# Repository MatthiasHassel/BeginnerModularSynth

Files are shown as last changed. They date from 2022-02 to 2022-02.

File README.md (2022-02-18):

# BeginnerModularSynth
DIY Modular Synth based on the Bela Board

I built this DIY Modular Synth for my bachelor thesis in February 2022. It is based on the Bela Board from the Augmented Instruments Laboratory in London and Eurorack compatible, where only voltages between 0V and +5V are evaluated correctly at the moment. However voltages beyond that limit won't harm the hardware and will be interpreted as 0V or +5V

With a "Default Patch" option it is possible to activate a fixed signal flow, where no patching is needed.

A lot of the code is inspired by materials based on a Master’s module “Music and Audio Programming”, taught by Dr Andrew McPherson in the School of Electronic Engineering and Computer Science. Thank you for making this lecture accessible for the public! 

C++ Realtime Programming with Bela:
https://www.youtube.com/watch?v=aVLRUyPBBJk&list=PLCrgFeG6pwQmdbB6l3ehC8oBBZbatVoz3

The Audio itself is not patchable for now, meaning the Audio signal flow is always Oscillator Out -> Filter In -> Filter Out -> Mixer In -> Mixer Out
For a next prototype however it is planned to change this to complete the modularity.

It's still a "work in progress" thing so I am happy about feedback and improvements!

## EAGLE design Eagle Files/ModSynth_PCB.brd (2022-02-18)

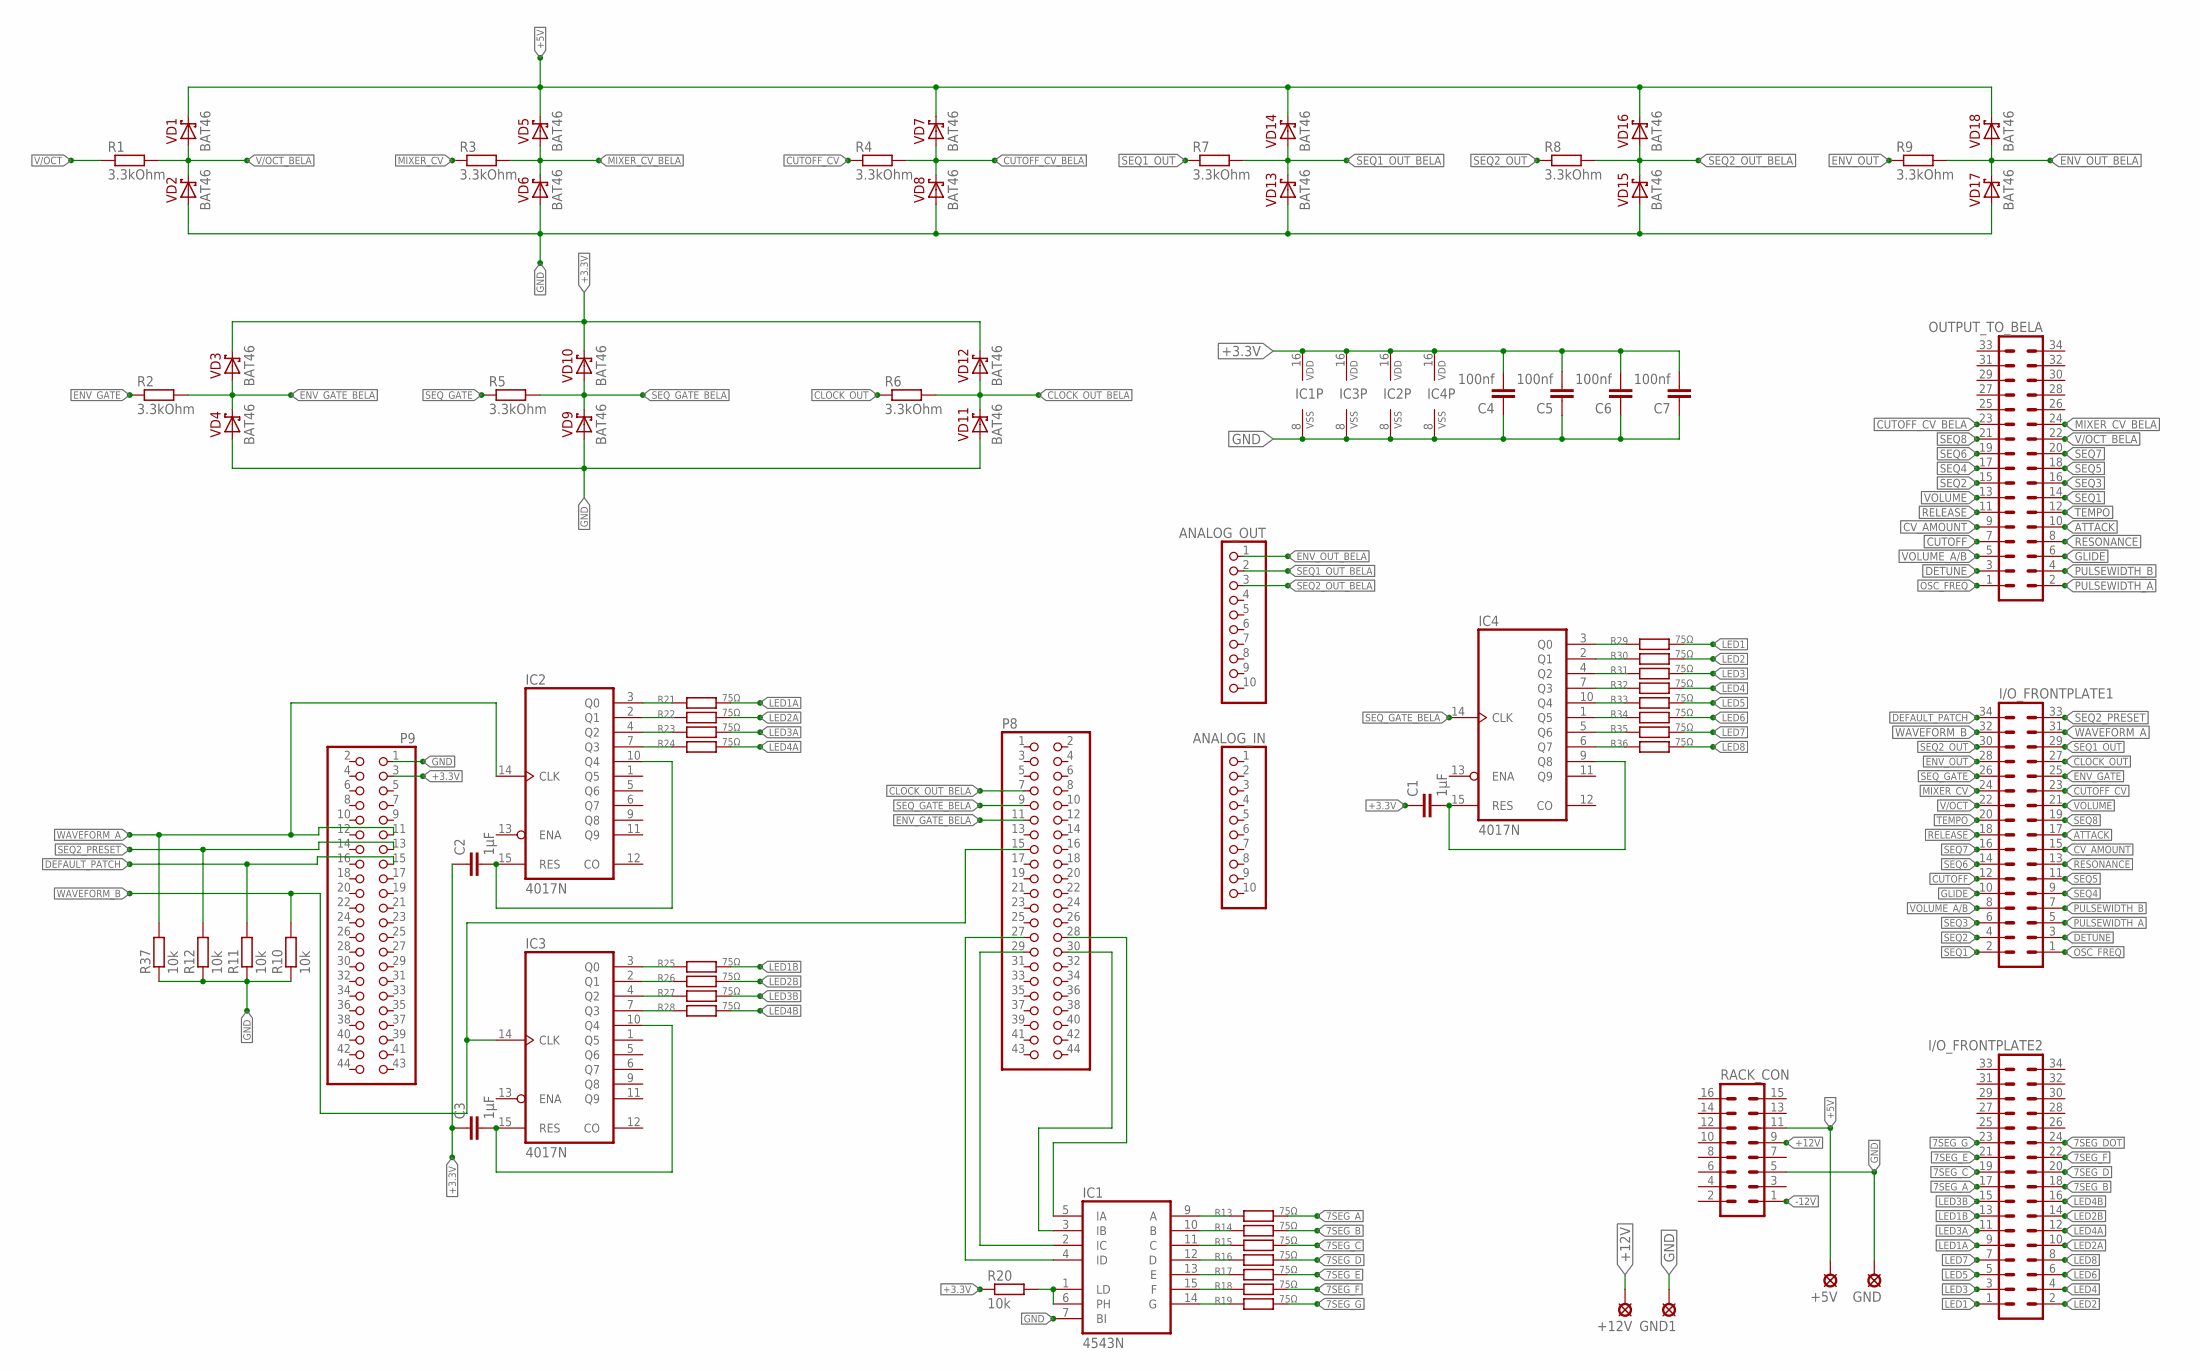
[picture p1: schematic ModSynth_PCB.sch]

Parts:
+5V, +12V: LSP10
ANALOG_IN: PINHD-1X10; 1X10
ANALOG_OUT: PINHD-1X10; 1X10
C1, C2, C3: 1µF; C025-025X050
C4, C5, C6, C7: 100nf; C025-025X050
GND, GND1: LSP10
I/O_FRONTPLATE1, I/O_FRONTPLATE2: ML34
IC1: 4543N; DIL16
IC2, IC3, IC4: 4017N; DIL16
OUTPUT_TO_BELA: ML34
P8, P9: PINHD-2X22; 2X22
R1, R2, R3, R4, R5, R6, R7, R8, R9: 3.3kOhm; 0204/7
R10, R11, R12, R20, R37: 10k; 0204/7
R13, R14, R15, R16, R17, R18, R19, R21, R22, R23, R24, R25, R26, R27, R28, R29, R30, R31, R32, R33, R34, R35, R36: 75Ω; 0204/7
RACK_CON: ML16
VD1, VD2, VD3, VD4, VD5, VD6, VD7, VD8, VD9, VD10, VD11, VD12, VD13, VD14, VD15, VD16, VD17, VD18: BAT46; DO35-7

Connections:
7SEG_A: I/O_FRONTPLATE2.17, R13.2
7SEG_B: I/O_FRONTPLATE2.18, R14.2
7SEG_C: I/O_FRONTPLATE2.19, R15.2
7SEG_D: I/O_FRONTPLATE2.20, R16.2
7SEG_DOT: I/O_FRONTPLATE2.24
7SEG_E: I/O_FRONTPLATE2.21, R17.2
7SEG_F: I/O_FRONTPLATE2.22, R18.2
7SEG_G: I/O_FRONTPLATE2.23, R19.2
+3.3V: C1.1, C2.1, C3.1, C4.2, C5.2, C6.2, C7.2, IC1.16 (VDD), IC2.16 (VDD), IC3.16 (VDD), IC4.16 (VDD), P9.3, R20.1, VD3.C, VD10.C, VD12.C
+5V: +5V.MP, RACK_CON.11, VD1.C, VD5.C, VD7.C, VD14.C, VD16.C, VD18.C
+12V: +12V.MP, RACK_CON.9
-12V: RACK_CON.1
ATTACK: I/O_FRONTPLATE1.17, OUTPUT_TO_BELA.10
CLOCK_OUT: I/O_FRONTPLATE1.27, R6.1
CLOCK_OUT_BELA: P8.7, R6.2, VD11.C, VD12.A
CUTOFF: I/O_FRONTPLATE1.12, OUTPUT_TO_BELA.7
CUTOFF_CV: I/O_FRONTPLATE1.23, R4.1
CUTOFF_CV_BELA: OUTPUT_TO_BELA.23, R4.2, VD7.A, VD8.C
CV_AMOUNT: I/O_FRONTPLATE1.15, OUTPUT_TO_BELA.9
DEFAULT_PATCH: I/O_FRONTPLATE1.34, P9.15, R11.2
DETUNE: I/O_FRONTPLATE1.3, OUTPUT_TO_BELA.3
ENV_GATE: I/O_FRONTPLATE1.25, R2.1
ENV_GATE_BELA: P8.11, R2.2, VD3.A, VD4.C
ENV_OUT: I/O_FRONTPLATE1.28, R9.1
ENV_OUT_BELA: ANALOG_OUT.1, R9.2, VD17.C, VD18.A
GLIDE: I/O_FRONTPLATE1.10, OUTPUT_TO_BELA.6
GND: C4.1, C5.1, C6.1, C7.1, GND.MP, GND1.MP, IC1.7 (BI), IC1.8 (VSS), IC2.8 (VSS), IC3.8 (VSS), IC4.8 (VSS), P9.1, R10.1, R11.1, R12.1, R37.1, RACK_CON.5, VD2.A, VD4.A, VD6.A, VD8.A, VD9.A, VD11.A, VD13.A, VD15.A, VD17.A
LED1: I/O_FRONTPLATE2.1, R29.2
LED1A: I/O_FRONTPLATE2.9, R21.2
LED1B: I/O_FRONTPLATE2.13, R25.2
LED2: I/O_FRONTPLATE2.2, R30.2
LED2A: I/O_FRONTPLATE2.10, R22.2
LED2B: I/O_FRONTPLATE2.14, R26.2
LED3: I/O_FRONTPLATE2.3, R31.2
LED3A: I/O_FRONTPLATE2.11, R23.2
LED3B: I/O_FRONTPLATE2.15, R27.2
LED4: I/O_FRONTPLATE2.4, R32.2
LED4A: I/O_FRONTPLATE2.12, R24.2
LED4B: I/O_FRONTPLATE2.16, R28.2
LED5: I/O_FRONTPLATE2.5, R33.2
LED6: I/O_FRONTPLATE2.6, R34.2
LED7: I/O_FRONTPLATE2.7, R35.2
LED8: I/O_FRONTPLATE2.8, R36.2
MIXER_CV: I/O_FRONTPLATE1.24, R3.1
MIXER_CV_BELA: OUTPUT_TO_BELA.24, R3.2, VD5.A, VD6.C
unnamed: IC1.9 (A), R13.1
unnamed: IC1.10 (B), R14.1
unnamed: IC1.11 (C), R15.1
unnamed: IC1.12 (D), R16.1
unnamed: IC1.13 (E), R17.1
unnamed: IC1.15 (F), R18.1
unnamed: IC1.14 (G), R19.1
unnamed: IC1.1 (LD), IC1.6 (PH), R20.2
unnamed: C2.2, IC2.10 (Q4), IC2.15 (RES)
unnamed: IC2.3 (Q0), R21.1
unnamed: IC2.2 (Q1), R22.1
unnamed: IC2.4 (Q2), R23.1
unnamed: IC2.7 (Q3), R24.1
unnamed: C3.2, IC3.10 (Q4), IC3.15 (RES)
unnamed: IC3.3 (Q0), R25.1
unnamed: IC3.2 (Q1), R26.1
unnamed: IC3.4 (Q2), R27.1
unnamed: IC3.7 (Q3), R28.1
unnamed: C1.2, IC4.9 (Q8), IC4.15 (RES)
unnamed: IC4.3 (Q0), R29.1
unnamed: IC4.2 (Q1), R30.1
unnamed: IC4.4 (Q2), R31.1
unnamed: IC4.7 (Q3), R32.1
unnamed: IC4.10 (Q4), R33.1
unnamed: IC4.1 (Q5), R34.1
unnamed: IC4.5 (Q6), R35.1
unnamed: IC4.6 (Q7), R36.1
unnamed: IC1.4 (ID), P8.27
unnamed: IC1.5 (IA), P8.28
unnamed: IC1.3 (IB), P8.30
unnamed: IC1.2 (IC), P8.29
OSC_FREQ: I/O_FRONTPLATE1.1, OUTPUT_TO_BELA.1
PULSEWIDTH_A: I/O_FRONTPLATE1.5, OUTPUT_TO_BELA.2
PULSEWIDTH_B: I/O_FRONTPLATE1.7, OUTPUT_TO_BELA.4
RELEASE: I/O_FRONTPLATE1.18, OUTPUT_TO_BELA.11
RESONANCE: I/O_FRONTPLATE1.13, OUTPUT_TO_BELA.8
SEQ1: I/O_FRONTPLATE1.2, OUTPUT_TO_BELA.14
SEQ1_OUT: I/O_FRONTPLATE1.29, R7.1
SEQ1_OUT_BELA: ANALOG_OUT.2, R7.2, VD13.C, VD14.A
SEQ2: I/O_FRONTPLATE1.4, OUTPUT_TO_BELA.15
SEQ2_OUT: I/O_FRONTPLATE1.30, R8.1
SEQ2_OUT_BELA: ANALOG_OUT.3, R8.2, VD15.C, VD16.A
SEQ2_PRESET: I/O_FRONTPLATE1.33, P9.13, R12.2
SEQ3: I/O_FRONTPLATE1.6, OUTPUT_TO_BELA.16
SEQ4: I/O_FRONTPLATE1.9, OUTPUT_TO_BELA.17
SEQ5: I/O_FRONTPLATE1.11, OUTPUT_TO_BELA.18
SEQ6: I/O_FRONTPLATE1.14, OUTPUT_TO_BELA.19
SEQ7: I/O_FRONTPLATE1.16, OUTPUT_TO_BELA.20
SEQ8: I/O_FRONTPLATE1.19, OUTPUT_TO_BELA.21
SEQ_GATE: I/O_FRONTPLATE1.26, R5.1
SEQ_GATE_BELA: IC4.14 (CLK), P8.9, R5.2, VD9.C, VD10.A
TEMPO: I/O_FRONTPLATE1.20, OUTPUT_TO_BELA.12
V/OCT: I/O_FRONTPLATE1.22, R1.1
V/OCT_BELA: OUTPUT_TO_BELA.22, R1.2, VD1.A, VD2.C
VOLUME: I/O_FRONTPLATE1.21, OUTPUT_TO_BELA.13
VOLUME_A/B: I/O_FRONTPLATE1.8, OUTPUT_TO_BELA.5
WAVEFORM_A: I/O_FRONTPLATE1.31, IC2.14 (CLK), P9.11, R37.2
WAVEFORM_B: I/O_FRONTPLATE1.32, IC3.14 (CLK), P8.15, R10.2

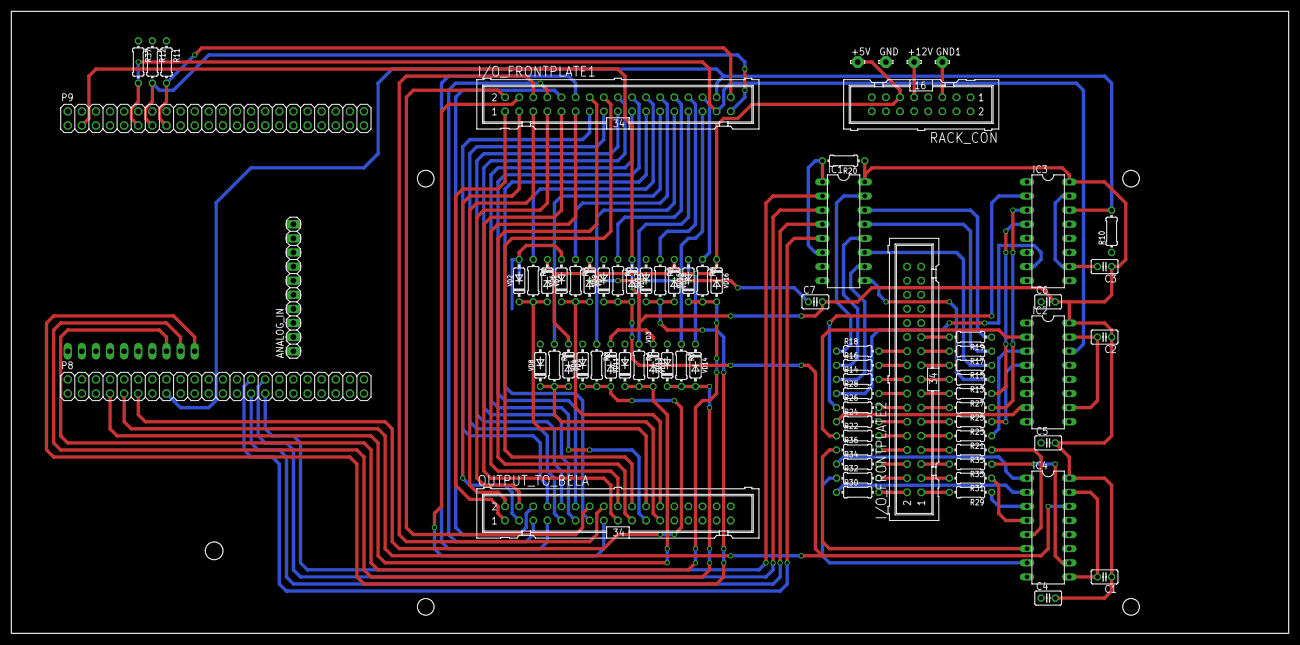
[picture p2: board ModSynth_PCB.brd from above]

Board: 2 copper layers, 230.0 x 112.0 mm, 78 parts (1 on the bottom side), 101 nets.

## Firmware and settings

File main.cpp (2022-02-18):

/*
____  _____ _        _
| __ )| ____| |      / \
|  _ \|  _| | |     / _ \
| |_) | |___| |___ / ___ \
|____/|_____|_____/_/   \_\
http://bela.io
*/

/*
//Bachelor-Project Matthias Hassel
//Hochschule Darmstadt
//31.01.2022
//Modular Synth Prototype 2
*/

/*
//Bela Settings:
//Sample Rate: 44.1kHz
//Blocksize: 16 Samples
//Multiplexer Capelet: Active, 64 Channels -> Jumper set to bypass Analog 4-7
//(Audio Expander: Active, Channel 6+7 set to In- & Outputs, Wires need to be added to the Capelet for 10x Gain) <-- Hardware not ready yet
*/

/*
//BCD Decoder Wiring:
//Phase -> 3,3V
//LatchDisable -> 3,3V
//Blanking -> GND
//Vss -> GND
//VDD -> 3,3V
*/

#include <Bela.h>
#include <unistd.h>
#include <libraries/ADSR/ADSR.h>
#include <libraries/math_neon/math_neon.h>
#include <libraries/Scope/Scope.h>
#include <array>

// instantiate the scope
Scope scope;

int gAudioFramesPerAnalogFrame = 0;
bool gIsStdoutTty;
unsigned int gPrintCount = 0;

/*IO*/
std::array<const unsigned int, 5> kButtonPin = {{6, 10, 7, 3, 5}};	// Pin number of the pushbutton
std::array<bool, 5> buttonState; 									// 0: Waveform A, 1: Waveform B, 2: SeqPreset, 3: Seq Gate, 4: Envelope Gate 
std::array<float, 23> input;
// State machine states
enum {
	kStateOpen = 0,
	kStateJustClosed,
	kStateClosed,
	kStateJustOpen
};
// State machine variables
std::array<int, 5> gDebounceState;
std::array<int, 5> gDebounceCounter;
int gDebounceInterval = 0;
bool switchPatch;
int kSwitchPin = 0;
/*********/
/*IO*/

/*CLOCK*/
unsigned int gClockInterval = 0;
unsigned int gClockCounter = 0;
const int kClockOutPin = 1;
float gTempo = 0;
float gHighPulseTime = 2205;
/*CLOCK*/

/*SEQUENCER*/
int gSequencer1Location = 0;
int gPresetSequence = 0;
int gNumPresets = 9;
std::array<int, 8> gSequencer1Buffer0{{40, 43, 45, 43, 50, 48, 50, 52}}; //Pink Floyd - On The Run, MIDI Notes
std::array<int, 8> gSequencer1Buffer1{{36, 38, 40, 42, 44, 46, 48, 50}}; //Olivier Messiaen Modes 1-7, MIDI Notes
std::array<int, 8> gSequencer1Buffer2{{36, 37, 39, 40, 42, 43, 45, 46}};
std::array<int, 8> gSequencer1Buffer3{{36, 37, 38, 40, 41, 42, 44, 45}};
std::array<int, 8> gSequencer1Buffer4{{36, 37, 38, 41, 42, 43, 46, 47}};
std::array<int, 8> gSequencer1Buffer5{{36, 37, 41, 42, 43, 47, 48, 49}};
std::array<int, 8> gSequencer1Buffer6{{36, 38, 40, 41, 42, 44, 46, 47}};
std::array<int, 8> gSequencer1Buffer7{{36, 37, 38, 39, 41, 42, 43, 44}};
std::array<int, 8> gSequencer1Buffer8{{36, 36, 36, 36, 36, 36, 36, 36}};
std::array<std::array<int, 8>, 9> gSequencer1Buffer{{gSequencer1Buffer0, gSequencer1Buffer1, gSequencer1Buffer2, gSequencer1Buffer3, gSequencer1Buffer4, gSequencer1Buffer5, gSequencer1Buffer6, gSequencer1Buffer7, gSequencer1Buffer8}};
/*SEQUENCER*/

/*OSC*/
float gFrequency = 60.0; 
float gInFreq = 0.0;
float gOscFreq = 0.0;
float gDetune = 0.0;
float gVolAB = 0.0;
float gGlide = 0.0;
float gRampDuration = 0.0;
float gFrequencyIncrement = 0.0;
float gLastInFreq1;
float gFrequency1; // Oscillator1 frequency (Hz)
float gPhase1; // Oscillator1 phase
float gFrequency2; //Oscillator2 frequency (Hz)
float gPhase2; //Oscillatro2 phase
float gInverseSampleRate;
float gPulseWidth1 = 0;
float gPulseWidth2 = 0;
enum osc_type1
{
	square1,	// 0
	sine1,		// 1
	triangle1,	// 2
	sawtooth1,	// 3
	numOscTypes1
};
enum osc_type2
{
	square2,	// 0
	sine2,		// 1
	triangle2,	// 2
	sawtooth2,	// 3
	numOscTypes2
};
unsigned int gOscType1 = 0;
unsigned int gOscType2 = 0;
/*OSC*/

/*ENVELOPE*/
ADSR envelope; // ADSR envelope
float gAttack = 0.1; // Envelope attack (seconds)
int gAttackTimeCounter = 0;
bool gAttackState = false;
float gDecay = 0.2; // Envelope decay (seconds)
float gRelease = 0.5; // Envelope release (seconds)
float gSustain = 1.0; // Envelope sustain level
float gEnvelopeAmp = 0.0;
/*ENVELOPE*/

/*FILTER*/
// Filter state and coefficients
float gLastX1 = 0, gLastX2 = 0;
float gLastY1 = 0, gLastY2 = 0;
float gA1 = 0, gA2 = 0;
float gB0 = 1, gB1 = 0, gB2 = 0;
float gCutoff = 10000;
float gQ = 0.707;
float gCutoffCVIN = 0.0;
float gCVAmount = 0.0;

// Calculate the filter coefficients based on the given parameters
void calculate_coefficients(float sampleRate, float frequency, float q)
{
    float k = tanf(M_PI * frequency / sampleRate);
    float norm = 1.0 / (1 + k / q + k * k);
    
    gB0 = k * k * norm;
    gB1 = 2.0 * gB0;
    gB2 = gB0;
    gA1 = 2 * (k * k - 1) * norm;
    gA2 = (1 - k / q + k * k) * norm;	
}
/*FILTER*/

/*MIXER*/
float gAmplitude = 0.3f; // Amplitude scaling for oscillator's envelope
float gVolume = 1.0f;
float gMixerCVIn = 0.0;
float gMixerAmp = 0.0;
/*MIXER*/

bool setup(BelaContext *context, void *userData)
{
	scope.setup(1, context->audioSampleRate);
	gClockInterval = 0.5 * context->audioSampleRate;
	
	if(context->multiplexerChannels == 0 || context->analogFrames == 0) {
                rt_printf("Please enable the Multiplexer Capelet to run this code.\n");
                return false;
        }

	gInverseSampleRate = 1.0 / context->audioSampleRate;
	gPhase1 = 0.0;
	
	// Set buttons pins as inputs
	for(int i = 0; i < kButtonPin.size(); i++)
	{	
	pinMode(context, 0, kButtonPin[i], INPUT);
	}
	pinMode(context, 0, kSwitchPin, INPUT);
	pinMode(context, 0, kClockOutPin, OUTPUT);
	
	gDebounceInterval = .05* context->digitalSampleRate;
	gDebounceState.fill(kStateOpen);
	gDebounceCounter.fill(0);
	buttonState.fill(1);
	
	if(context->analogFrames)
		gAudioFramesPerAnalogFrame = context->audioFrames / context->analogFrames;
	
	gIsStdoutTty = isatty(1); // Check if stdout is a terminal

    // Set ADSR parameters
	envelope.setAttackRate(gAttack * context->audioSampleRate);
	envelope.setDecayRate(gDecay * context->audioSampleRate);
	envelope.setReleaseRate(gRelease * context->audioSampleRate);
	envelope.setSustainLevel(gSustain);
	
	return true;
}

void render(BelaContext *context, void *userData)
{
	/*SERIAL MONITOR*/
	/*
    gPrintCount += context->analogFrames;
	if(gPrintCount >= (unsigned int)(context->analogSampleRate * 0.1)) 
	{
	    gPrintCount = 0;
	    if(gIsStdoutTty)
	    rt_printf("\e[1;1H\e[2J");      // Command to clear the screen (on a terminal)
	    for (unsigned int i = 0; i < 24; i++)
	    {
			rt_printf("Input %d: ", i);
	     	rt_printf("%f ", input[i]);
	        if(i%8 == 0)
	        rt_printf("\n");
	    }
	}
	*/
	/*SERIAL MONITOR*/                   
	            			
	        
	for(unsigned int n = 0; n < context->audioFrames; n++) 
	{
		/* Go through each multiplexer setting of each analog input and display the value */
	    for(unsigned int i = 0; i < 3; i++) 
	    {
	    	for(unsigned int muxChannel = 0; muxChannel < context->multiplexerChannels; muxChannel++) 
	    	{
	             input[muxChannel + (8*i)] = multiplexerAnalogRead(context, i, muxChannel);
	        }
	    }
	    
        //make sure that PotValues reach from 0.0 to 1.0
		for(unsigned int i = 0; i < 22; i++)
		{
			input[i] = input[i]*(4.096/3.3);
			if (input[i] < 0.0003)
			{
				input[i] = 0.0;
			}
			if (input[i] > 1.0)
			{
				input[i] = 1.0;
			}
		}

        //scale each parameter   
		gOscFreq = input[0]*1000.0;
		gPulseWidth1 = input[1] * 4.0 - 2.0;
		gDetune = input[2]*0.04;
		gPulseWidth2 = input[3] * 4.0 - 2.0;
		gVolAB = input[4];
		gGlide = input[5]*0.2;
		gCutoff = map(input[6], 0, 1, 80, 15000);
		gQ = map(input[7], 0, 1, 0.5, 10);
		gCVAmount = input[8]; 
		gAttack = input[9]*0.7 + 0.001;
		gRelease = input[10]*2.0;
		gTempo = map(input[11], 0, 1, 40, 208)*4.0;
		gVolume = input[12];
		gMixerCVIn = multiplexerAnalogRead(context, 3, 0);
		
		switchPatch = digitalRead(context, n, kSwitchPin);
		
		/*CLOCK*/
			gClockInterval = 60.0 * context->audioSampleRate / gTempo;
			if(++gClockCounter >= gClockInterval)
			{
				gClockCounter = 0;
				if(switchPatch)
				{
					gSequencer1Location++;
					if(gSequencer1Location >= gSequencer1Buffer0.size())
					{
						gSequencer1Location = 0;
					}
					// ...turn ON the envelope's gate
					envelope.gate(true);
					gAttackState = true;
					gAttackTimeCounter = 0;	
				}
			}
			if(!switchPatch)
			{
				if(gClockCounter < gHighPulseTime)
				{
					digitalWriteOnce(context, n, kClockOutPin, HIGH);
				}
				else
				{
					digitalWrite(context, n, kClockOutPin, LOW);
				}
			}
		/*CLOCK*/
		
		/*BUTTONS + GATES + SWITCH*/	
		for(unsigned int n = 0; n < context->digitalFrames; n++) 
		{ 
			// Read the button state
   			for(int i = 0; i < kButtonPin.size(); i++)
	   		{
	   			buttonState[i] = digitalRead(context, n, kButtonPin[i]);
	   			
	   			if(gDebounceState[i] == kStateOpen) {
	   			// Button is not pressed, could be pressed anytime
	   			// Input: look for switch closure
	   			if (buttonState[i] == 1)
	   			{
	   				gDebounceState[i] = kStateJustClosed;
	   				gDebounceCounter[i] = 0;
	               
	                if (i == 0) //OSC1 Mode
	                {
	                    // Change oscillator type
						gOscType1 += 1;
						// Wrap around number of different oscillator types if counter is out of bounds
						if(gOscType1 >= numOscTypes1)
							gOscType1 = 0;
						rt_printf("Oscillator1 type: %d\n", gOscType1);
	                }
	                if (i == 1) //OSC2 Mode
	                {
	                    // Change oscillator type
						gOscType2 += 1;
						// Wrap around number of different oscillator types if counter is out of bounds
						if(gOscType2 >= numOscTypes2)
							gOscType2 = 0;
						rt_printf("Oscillator2 type: %d\n", gOscType2);
				    }
				    if (i == 2)
				    {
					    gPresetSequence++;
                        //Wrap around number of different Sequencer Presets if counter is out of bounds
					    if(gPresetSequence >= gNumPresets)
						{
							gPresetSequence = 0;
						}
				    }
	                if (i == 3) //SeqPreset
	                {
	                	if(!switchPatch)
	                	{
	                		// ...turn ON the envelope's gate
							envelope.gate(true);
							gAttackState = true;
							gAttackTimeCounter = 0;	
	                	}
	                }
	                if (i == 4)
	                {
	                	if(!switchPatch)
	                	{
		                	gSequencer1Location++;
							if(gSequencer1Location >= gSequencer1Buffer0.size())
							{
								gSequencer1Location = 0;
							}	
	                	}
	                }
	   			}
	   		}
	   		else if(gDebounceState[i] == kStateJustClosed) {
	   			// Button was just pressed, wait for debounce
	   			// Input: run counter, wait for timeout
	   			if(++gDebounceCounter[i] >= gDebounceInterval)
	   			{
	   				gDebounceState[i] = kStateClosed;
	   			}
	   		}
	   		else if(gDebounceState[i] == kStateClosed) {
	   			// Button is pressed, could be released anytime
	   			// Input: look for switch opening
	   			if(buttonState[i] != 1)
	   			{
	   				gDebounceState[i] = kStateJustOpen;
	   				gDebounceCounter[i] = 0;
	   			}
	   		}
	   		else if(gDebounceState[i] == kStateJustOpen) {
	   			// Button was just released, wait for debounce
	   			// Input: run counter, wait for timeout
	   			if(++gDebounceCounter[i] >= gDebounceInterval)
	   			{
	   				gDebounceState[i] = kStateOpen;
	   			}
	   		}
	   		}
		}
		/*BUTTONS + GATES + SWITCH*/

		/*SEQUENCER*/
		float Seq0Out = input[gSequencer1Location + 13];
		float Seq1Out = 440*powf(2.0, (gSequencer1Buffer[gPresetSequence][gSequencer1Location] - 69.0) / 12.0); //convert MIDI to Frequency
		Seq1Out = log2(Seq1Out/55)/4.096;
		float Seq0OutScaled = Seq0Out * (4.096/5.0);
		float Seq1OutScaled = Seq1Out * (4.096/5.0);
		if(!switchPatch)
		{
			for(unsigned int n = 0; n < context->analogFrames; n++) 
			{
			analogWriteOnce(context, n, 2, Seq1OutScaled);
			analogWriteOnce(context, n, 1, Seq0OutScaled);
			}
		}
		/*SEQUENCER*/
		
		/*OSC*/
		if(switchPatch)
		{
			gInFreq = 55.0 * powf(2.0, Seq1Out*4.096);
		}
		if(!switchPatch)
		{
			gInFreq = 55.0 * powf(2.0, input[22]*4.096);
		}
		gRampDuration = gGlide * context->audioSampleRate;
		if (gGlide == 0)
		{
			gFrequencyIncrement = 0;
			gLastInFreq1 = gInFreq;
			gFrequency = gInFreq + gOscFreq;
		}
		else
		{
			gFrequencyIncrement =  (gInFreq - gLastInFreq1) / gRampDuration;
			gLastInFreq1 = gLastInFreq1 + gFrequencyIncrement;
		}
		gFrequency = gLastInFreq1 + gOscFreq + gFrequencyIncrement;
		
		// Calculate output based on the selected oscillator mode
		float Osc1Out;
		switch(gOscType1) {
			default:
			// SINEWAVE
			case sine1:
				Osc1Out = sinf_neon(gPhase1);
				break;
			// TRIANGLE WAVE
			case triangle1:
				if (gPhase1 > 0) {
				      Osc1Out = -1 + (2 * gPhase1 / (float)M_PI);
				} else {
				      Osc1Out = -1 - (2 * gPhase1/ (float)M_PI);
				}
				break;
			// SQUARE WAVE
			case square1:
				if (gPhase1 > gPulseWidth1) {
				      Osc1Out = 1;
				} else {
				      Osc1Out = -1;
				}
				Osc1Out = Osc1Out * 0.5;
				break;
			// SAWTOOTH
			case sawtooth1:
				Osc1Out = 1 - (1 / (float)M_PI * gPhase1);
				Osc1Out = Osc1Out * 0.5;
				break;
		}
		
		float Osc2Out;
		switch(gOscType2) {
			default:
			// SINEWAVE
			case sine2:
				Osc2Out = sinf_neon(gPhase2);
				break;
			// TRIANGLE WAVE
			case triangle2:
				if (gPhase2 > 0) {
				      Osc2Out = -1 + (2 * gPhase2 / (float)M_PI);
				} else {
				      Osc2Out = -1 - (2 * gPhase2/ (float)M_PI);
				}
				break;
			// SQUARE WAVE
			case square2:
				if (gPhase2 > gPulseWidth2) {
				      Osc2Out = 1;
				} else {
				      Osc2Out = -1;
				}
				Osc2Out = Osc2Out * 0.5;
				break;
			// SAWTOOTH
			case sawtooth2:
				Osc2Out = 1 - (1 / (float)M_PI * gPhase2);
				Osc2Out = Osc2Out * 0.5;
				break;
		}
		gFrequency1 = gFrequency * (1.0 + gDetune);
		gFrequency2 = gFrequency * (1.0 - gDetune);
		// Compute phase
		gPhase1 += 2.0f * (float)M_PI * gFrequency1 * gInverseSampleRate;
		if(gPhase1 > M_PI)
			gPhase1 -= 2.0f * (float)M_PI;
			
		gPhase2 += 2.0f * (float)M_PI * gFrequency2 * gInverseSampleRate;
		if(gPhase2 > M_PI)
			gPhase2 -= 2.0f * (float)M_PI;
		
		float OscOut = Osc1Out*(1 - gVolAB) + Osc2Out*gVolAB;
		/* Audio Patching, doesn't work yet
		if(!switchPatch)
		{
			analogWriteOnce(context, n/2, 6, OscOut*0.7);
		}
		*/
		/*OSC*/
		
		/*FILTER*/
		float CutoffCVIn;
		float FilterIn;
		/* Audio Patching, doesn't work yet
		if(switchPatch)
		{
			FilterIn = 0.5 * OscOut;
			CutoffCVIn = (Seq0Out - 0.5) * 20000;
		}
		if(!switchPatch)
		{
			FilterIn = analogRead(context, n/2, 6);
			CutoffCVIn = (input[23] - 0.5) * 20000;	
		}
		*/
		FilterIn = 0.5 * OscOut;
		if(switchPatch)
		{
			CutoffCVIn = (Seq0Out - 0.5) * 20000;
		}
		if(!switchPatch)
		{
			CutoffCVIn = (input[23] - 0.5) * 20000;	
		}
		gCutoff = gCutoff + (CutoffCVIn * gCVAmount);
		if (gCutoff > 15000)
		{
			gCutoff = 15000;
		}
		if (gCutoff < 80)
		{
			gCutoff = 80;
		}
		
		// Calculate initial coefficients
		calculate_coefficients(context->audioSampleRate, gCutoff, gQ); 
        float FilterOut = gB0*FilterIn + gB1*gLastX1 + gB2*gLastX2 - gA1*gLastY1 - gA2*gLastY2;

		gLastX2 = gLastX1;
		gLastX1 = FilterIn;
		gLastY2 = gLastY1;
		gLastY1 = FilterOut;
		/* Audio Patching, doesn't work yet
		if(!switchPatch)
		{
			analogWriteOnce(context, n/2, 7, FilterOut);
		}
		*/
		/*FILTER*/
		
		/*ENVELOPE*/	
		envelope.setAttackRate(gAttack * context->audioSampleRate);
		envelope.setReleaseRate(gRelease * context->audioSampleRate);
		if(gAttackState)
		{
			gAttackTimeCounter++;
			if(gAttackTimeCounter >= (gAttack * context->audioSampleRate))
			{
				envelope.gate(false);
				gAttackState = false;
			}
		}
		
		gEnvelopeAmp = gAmplitude * envelope.process();
		if(!switchPatch)
		{
			for(unsigned int n = 0; n < context->analogFrames; n++) 
			{
			analogWriteOnce(context, n, 0, gEnvelopeAmp * (4.096/5.0));
			}
		}
		/*ENVELOPE*/
		
		/*MIXER*/
		float MixerIn;
		/* Audiopatching, doesn't work yet
		if(switchPatch)
		{
			MixerIn = FilterOut;
			gMixerAmp = gEnvelopeAmp;
		}
		if(!switchPatch)
		{
			MixerIn = analogRead(context, n/2, 7);
			gMixerAmp = gMixerCVIn;
		}
		*/
		MixerIn = FilterOut;
		if(switchPatch)
		{
			gMixerAmp = gEnvelopeAmp;
		}
		if(!switchPatch)
		{
			gMixerAmp = gMixerCVIn;
		}
		float out = MixerIn * gVolume * gMixerAmp;
		// Write output to different channels
		for(unsigned int channel = 0; channel < 2; channel++) {
			audioWrite(context, n, channel, out*3);
		}
		/*MIXER*/
		scope.log(FilterOut);
	}
}

void cleanup(BelaContext *context, void *userData)
{
}
